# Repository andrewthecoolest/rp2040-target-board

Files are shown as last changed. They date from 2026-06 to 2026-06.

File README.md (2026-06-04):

# RP2040 Target Board

A ChipWhisperer-compatible target board built around the Raspberry Pi RP2040.

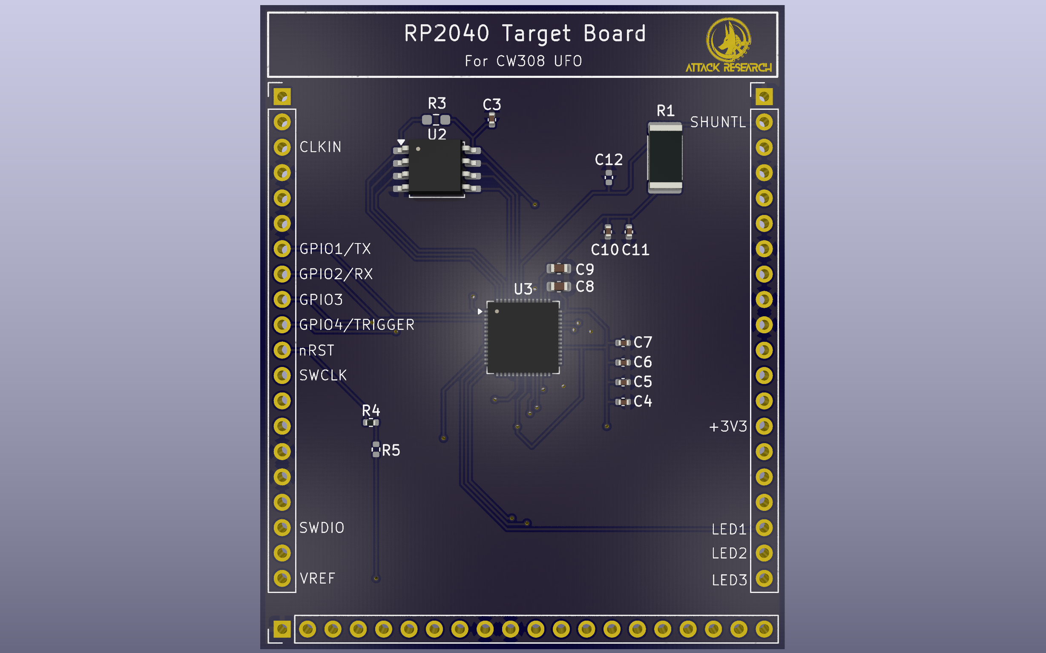
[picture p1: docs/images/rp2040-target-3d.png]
board


## Overview

This board connects an RP2040 with shunt to the CW308 UFO.

## Features

- RP2040 dual-core Arm Cortex-M0+ microcontroller
- 16MB QSPI flash
- ChipWhisperer 60-pin UFO308 target connector
- 5Ω shunt (changable to anything < 10Ω)
- 2-layer PCB
- Made with love

## Ordering

If you want to make your own, Gerbers are in `fab/gerbers/`. I made it with JLCPCB default 2-layer settings, so I included CPL and BOM for JLCPCB. For JLCPCB specifically, I've already zipped the gerbers and drill.

## Repository Structure

```
├── hardware/
│   ├── rp2040-target.kicad_pro     KiCad project
│   ├── rp2040-target.kicad_pcb     PCB
│   ├── rp2040-target.kicad_sch     Main schematic
│   ├── rp2040-target.kicad_wks     AR template
│   ├── RP2040.kicad_sch            RP2040 sub-sheet
│   ├── Flash.kicad_sch             Flash sub-sheet
│   └── libs/
│       ├── Conn_UFO308.kicad_sym   UFO308 target schematic symbol
│       └── UFO308.pretty/          UFO308 target footprint
│
├── fab/
│   ├── gerbers/                    Gbrs and drill
│   ├── 2040-target-fab.zip         Gerber and drill zip
│   ├── jlcpcb_bom.csv              BOM
│   └── jlcpcb_cpl.csv              CPL
│
└── docs/
    ├── schematic.pdf
    └── images/
```

## Andrew Acknowledgement

Start Message.
    My name is Andrew ᶘ ◕ᴥ◕ᶅ
Conclude Message.

## License

Copyright Attack Research 2026. Licensed under the [CERN Open Hardware Licence Version 2 - Permissive (CERN-OHL-P v2)](LICENSE).

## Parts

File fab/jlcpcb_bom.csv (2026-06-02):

Comment | Designator | Footprint | JLCPCB Part #
100nF | C3, C4, C5, C6, C7, C10, C11 | C_0402_1005Metric | C1525
1uF | C8, C9 | C_0603_1608Metric | C1592
DNP | C12 | C_0402_1005Metric
5Ω Shunt | R1 | R_2512_6332Metric | C5123609
DNP | R3 | R_0603_1608Metric_Pad0.98x0.95mm_HandSolder
0Ω | R4 | R_0402_1005Metric | C17168
DNP | R5 | R_0402_1005Metric
W25Q128JVS | U2 | SOIC-8_5.3x5.3mm_P1.27mm | C97521
RP2040 | U3 | QFN-56-1EP_7x7mm_P0.4mm_EP3.2x3.2mm | C2040

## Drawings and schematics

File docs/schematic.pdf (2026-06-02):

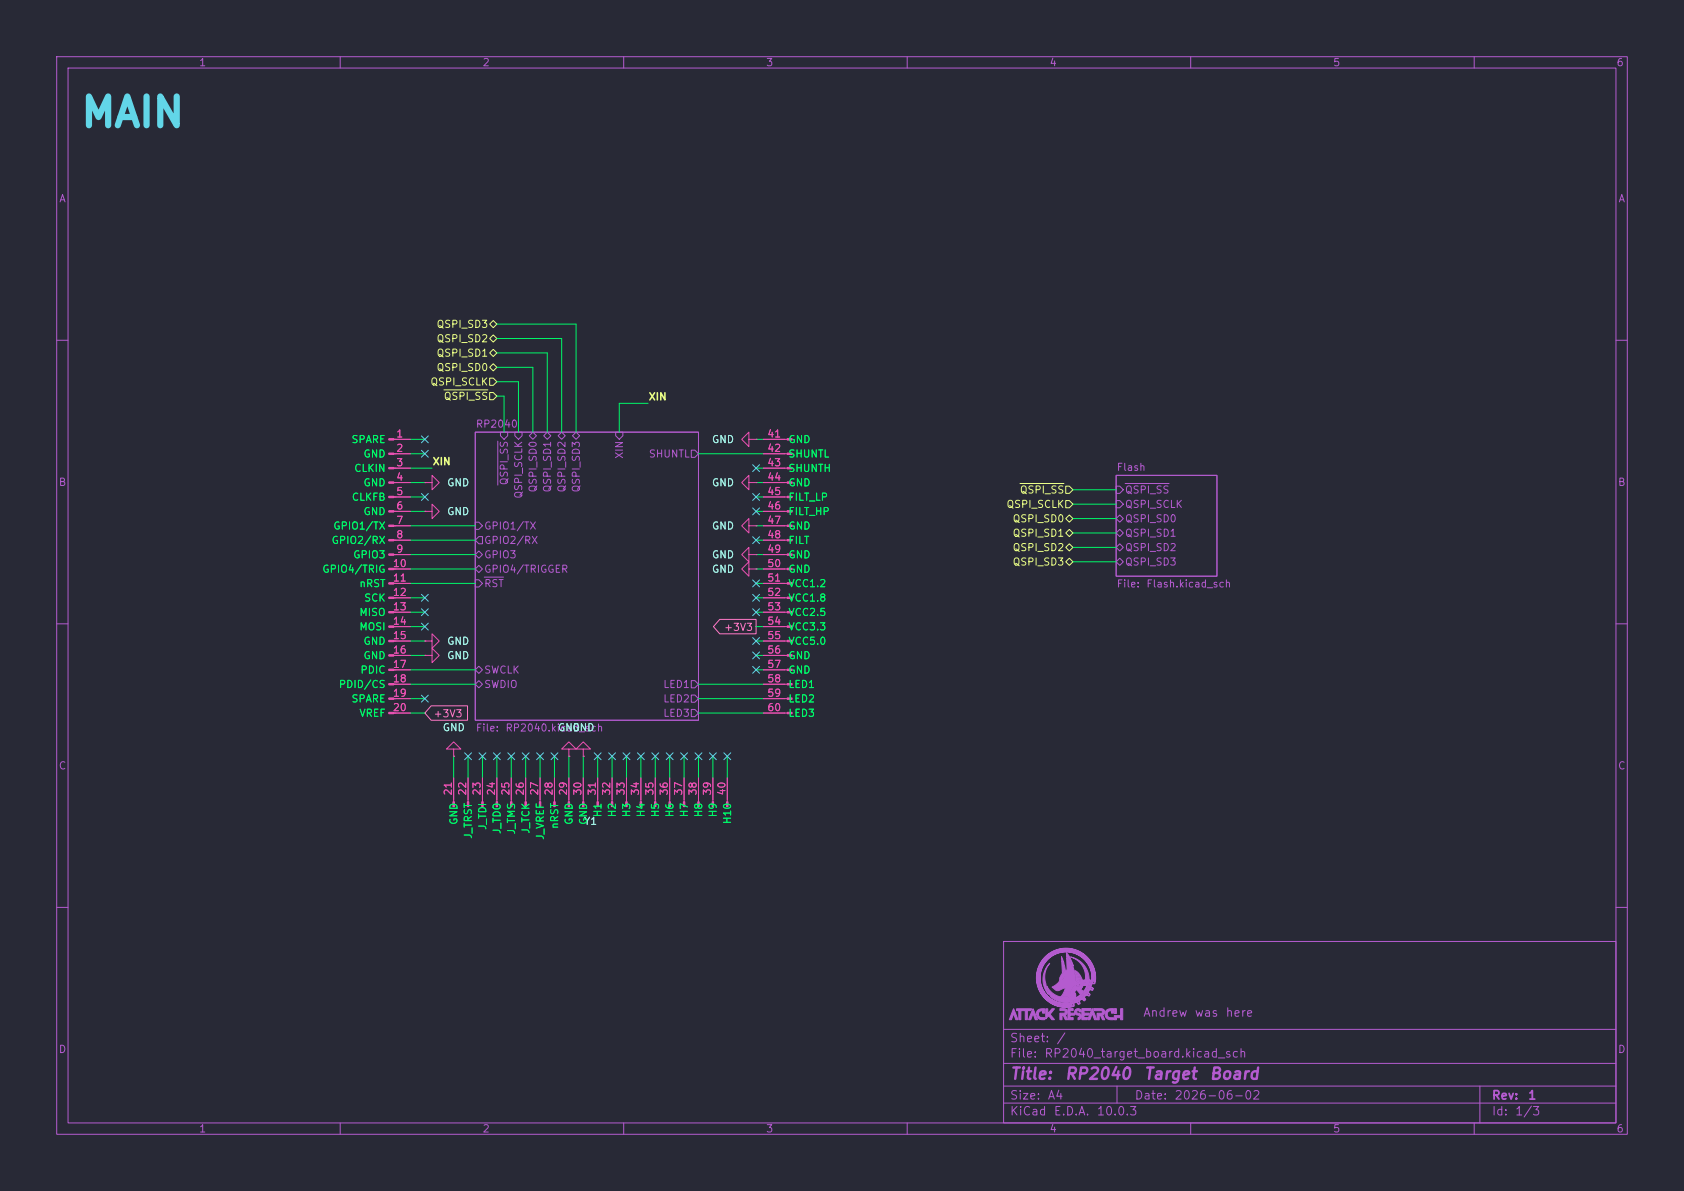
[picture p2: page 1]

SPARE 1 GND 2 CLKIN 3 GND 4 CLKFB 5 GND 6 GPIO1/TX 7 GPIO2/RX 8 GPIO3 9 GPIO4/TRIG 10

nRST 11
SCK 12 MISO 13 MOSI 14 GND 15 GND 16 PDIC 17 PDID/CS 18

Size: A4 | Rev: 1
KiCad E.D.A. 10.0.3 | Id: 1/3

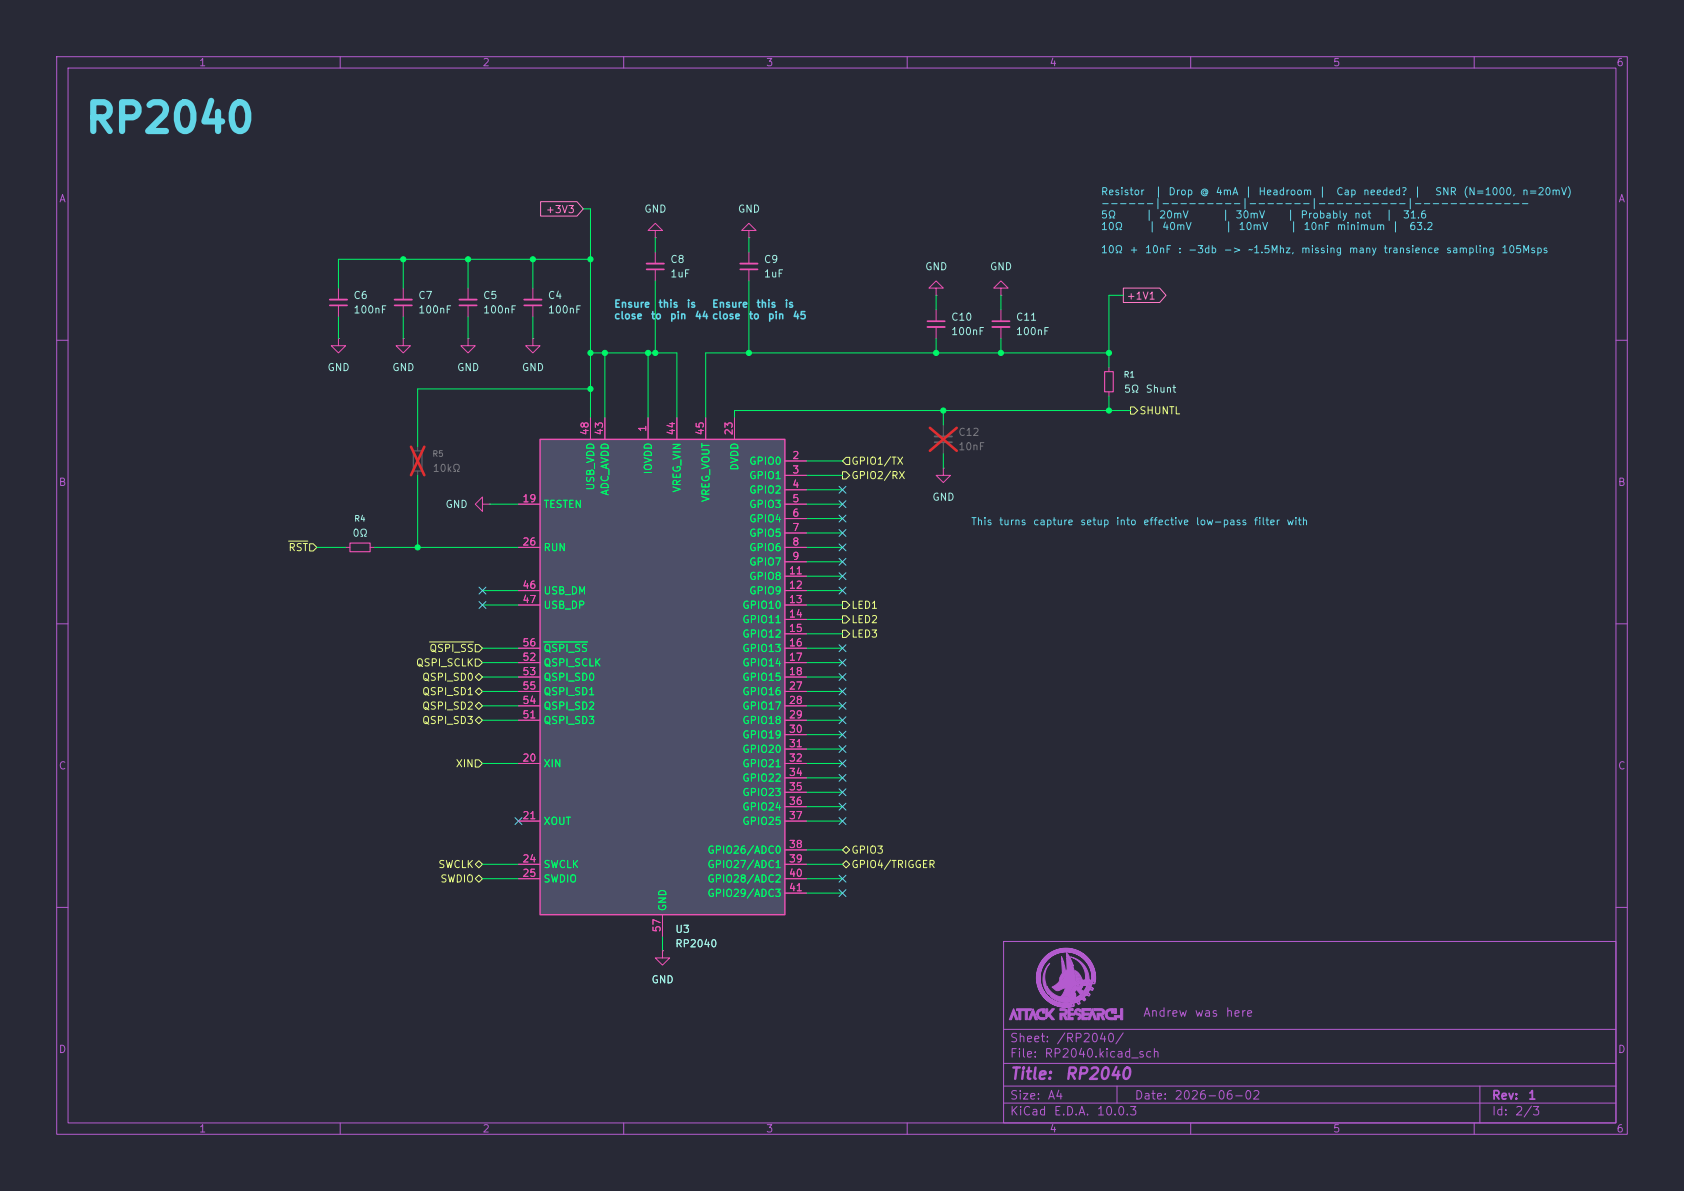
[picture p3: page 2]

This turns capture setup into effective low-pass filter with RP2040

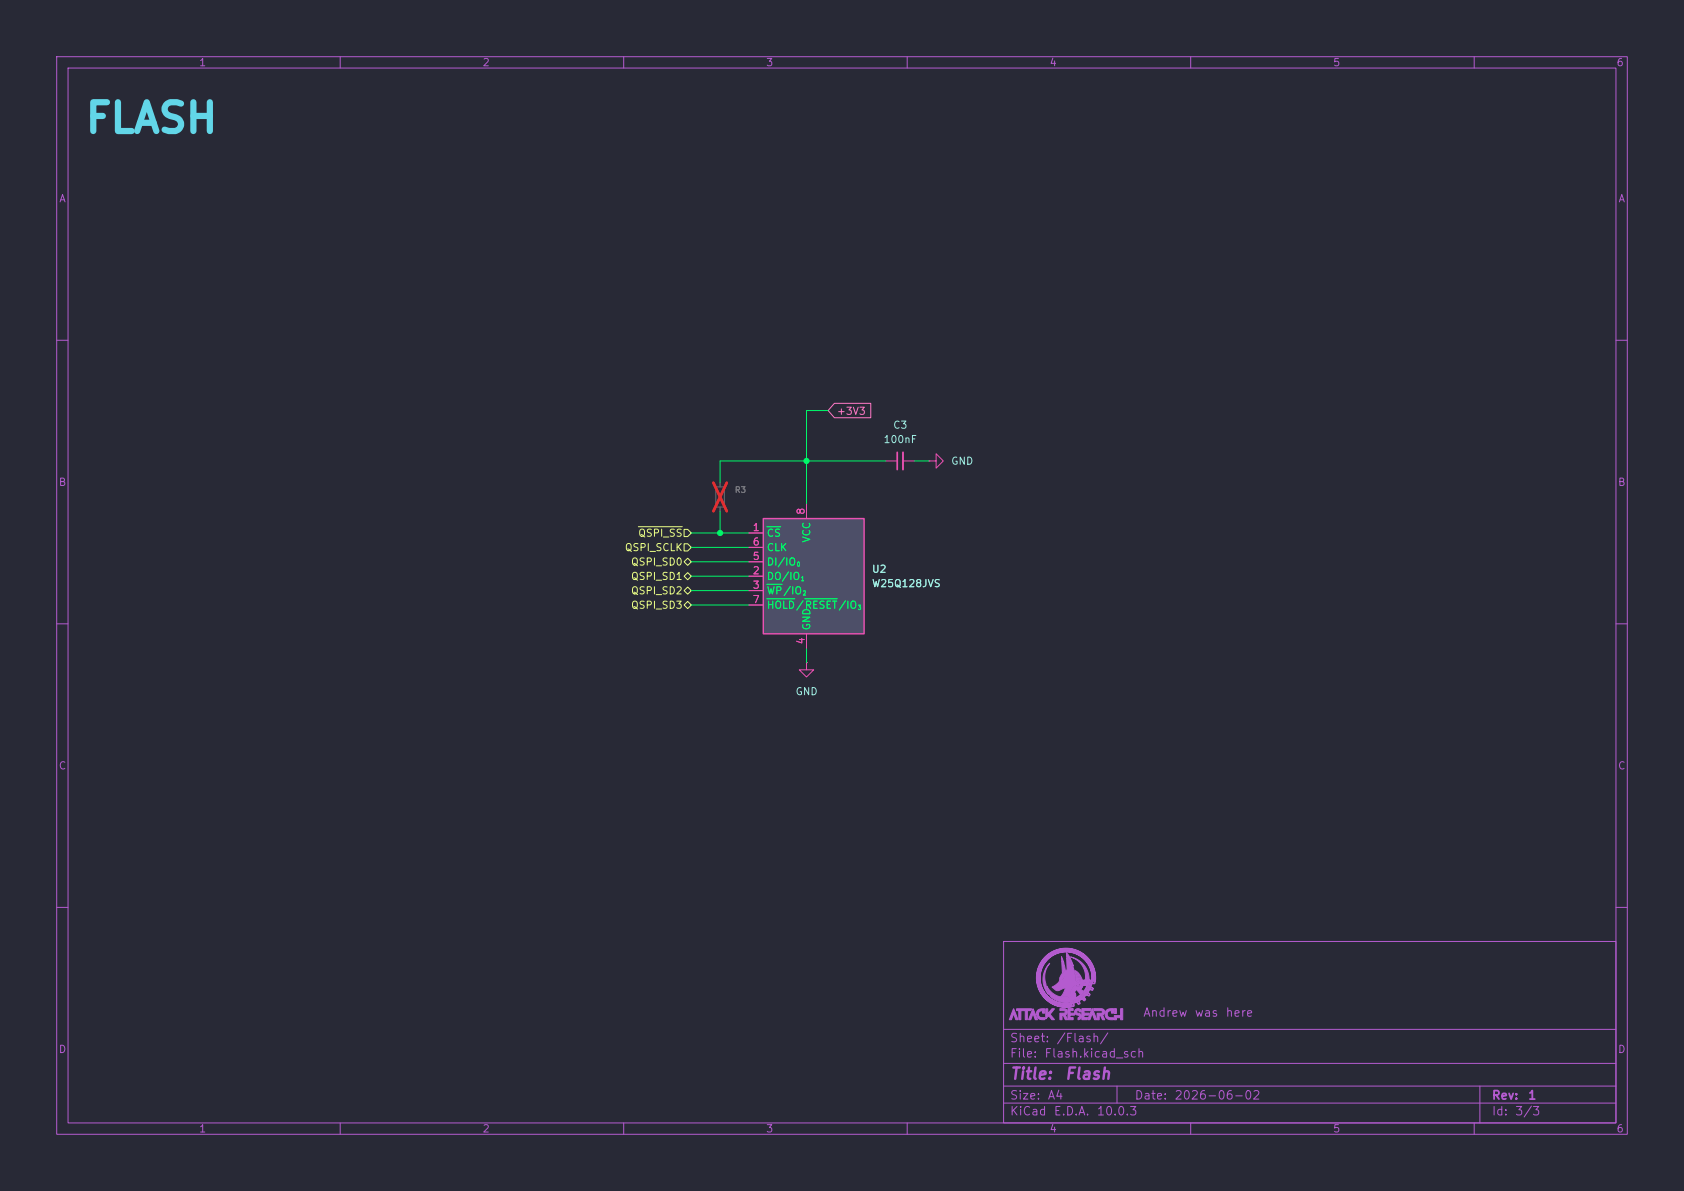
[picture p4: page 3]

4 DI/IO0 5 CLK 6 HOLD/RESET/IO3 7 VCC

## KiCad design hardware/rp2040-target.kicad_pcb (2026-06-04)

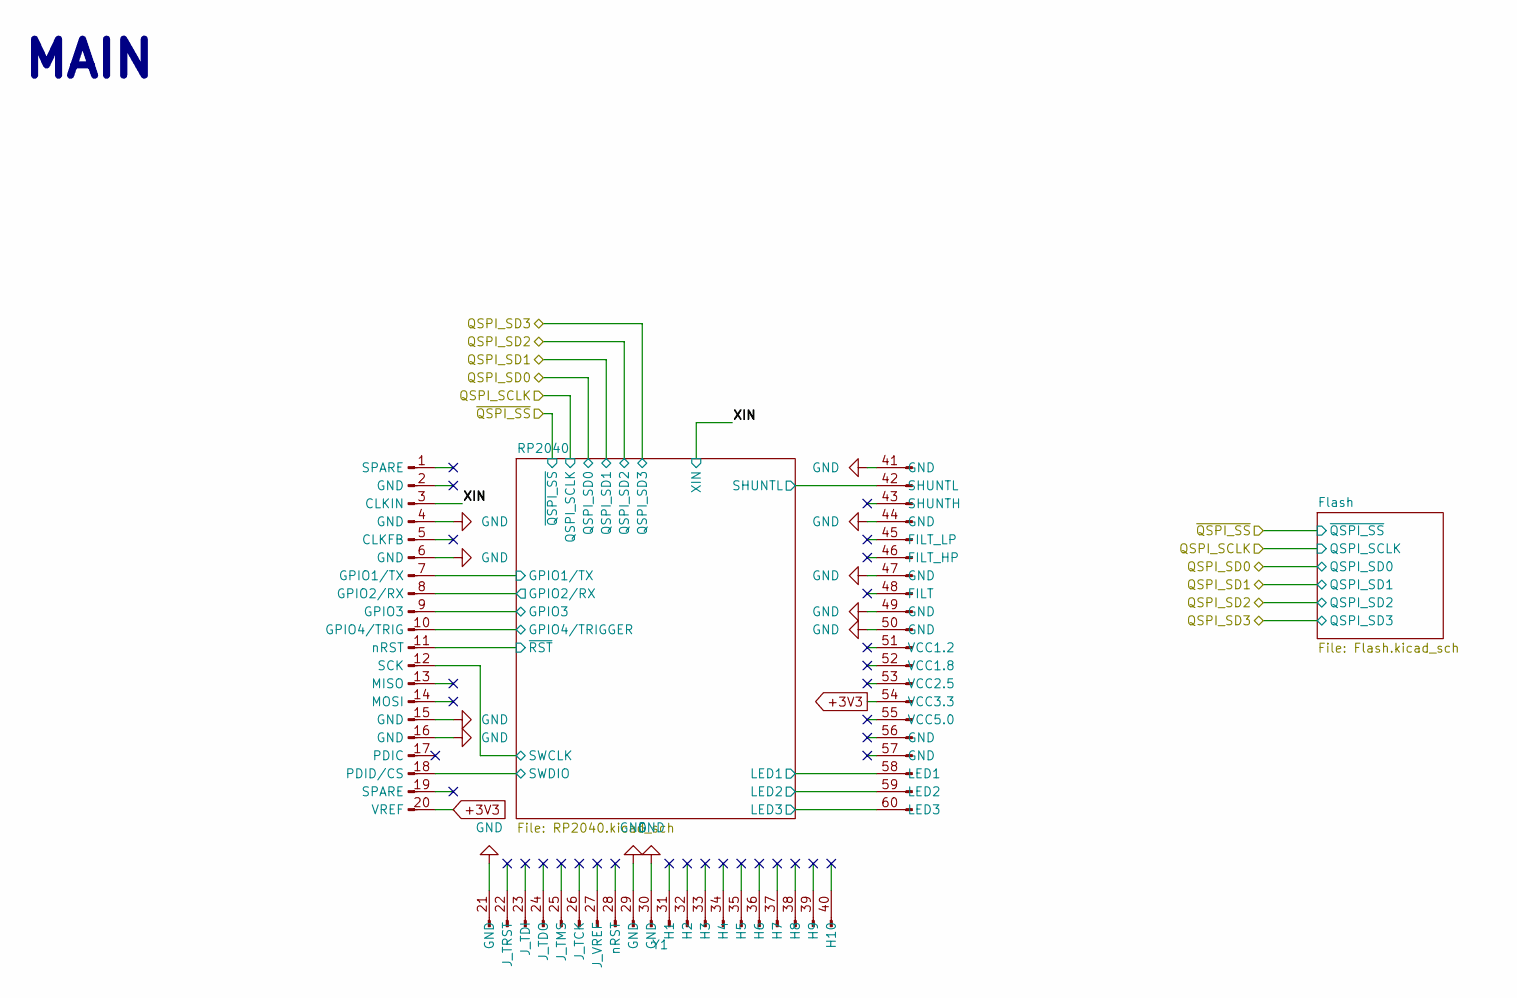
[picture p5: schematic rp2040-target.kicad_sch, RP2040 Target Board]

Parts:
Y1: Conn_UFO308_Target

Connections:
+3V3: Y1.20 (VREF), Y1.54 (VCC3.3); also elsewhere on the board
/RP2040/GPIO1/TX: Y1.7 (GPIO1/TX); also elsewhere on the board
/RP2040/GPIO2/RX: Y1.8 (GPIO2/RX); also elsewhere on the board
/RP2040/GPIO3: Y1.9 (GPIO3); also elsewhere on the board
/RP2040/GPIO4/TRIGGER: Y1.10 (GPIO4/TRIG); also elsewhere on the board
/RP2040/LED1: Y1.58 (LED1); also elsewhere on the board
/RP2040/LED2: Y1.59 (LED2); also elsewhere on the board
/RP2040/LED3: Y1.60 (LED3); also elsewhere on the board
/RP2040/SHUNTL: Y1.42 (SHUNTL); also elsewhere on the board
/RP2040/SWCLK: Y1.12 (SCK); also elsewhere on the board
/RP2040/SWDIO: Y1.18 (PDID/CS); also elsewhere on the board
/RP2040/~RST: Y1.11 (nRST); also elsewhere on the board
/XIN: Y1.3 (CLKIN); also elsewhere on the board
GND: Y1.4 (GND), Y1.6 (GND), Y1.15 (GND), Y1.16 (GND), Y1.21 (GND), Y1.29 (GND), Y1.30 (GND), Y1.41 (GND), Y1.44 (GND), Y1.47 (GND), Y1.49 (GND), Y1.50 (GND); also elsewhere on the board

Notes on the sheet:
MAIN

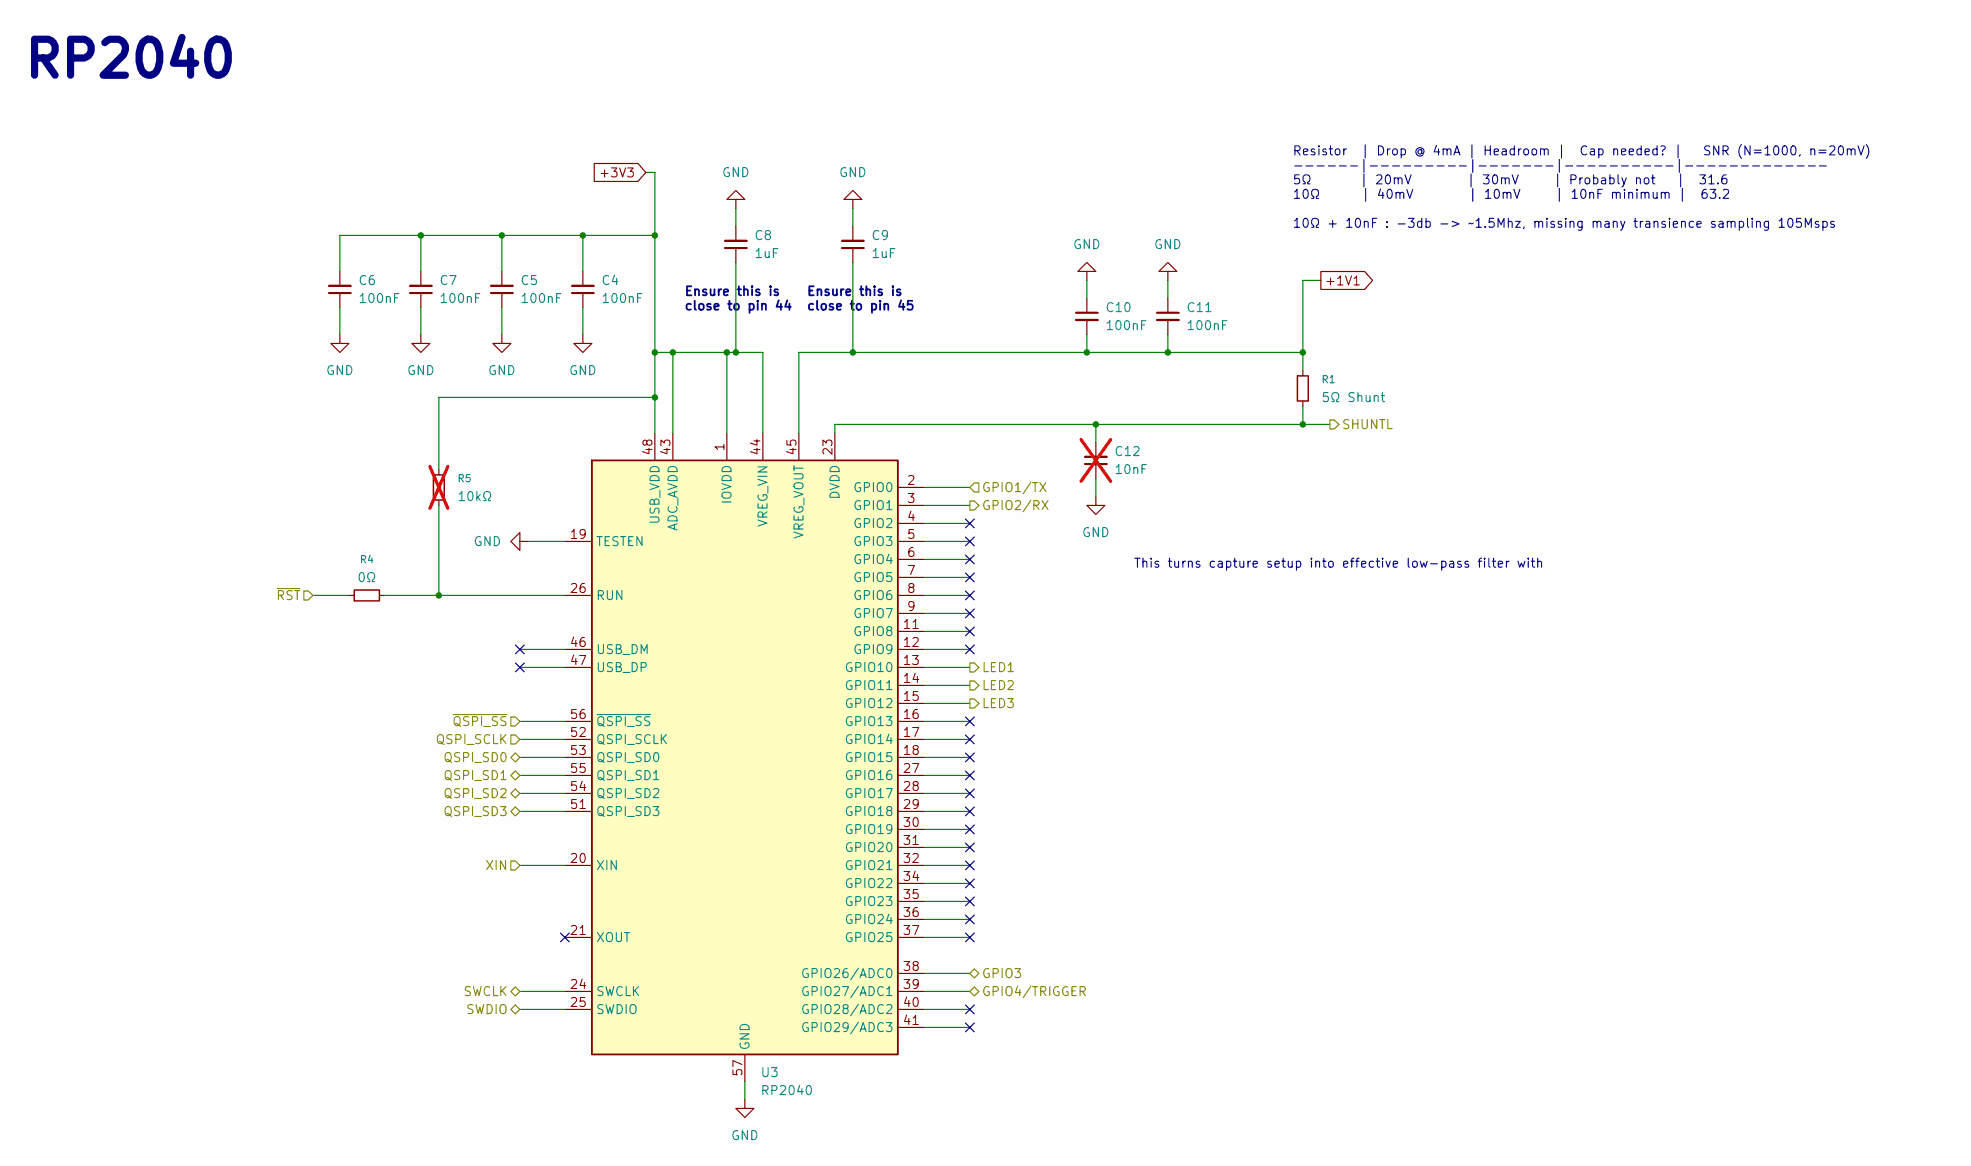
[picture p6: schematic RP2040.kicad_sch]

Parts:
C4, C5, C6, C7, C10, C11: 100nF; C_0402_1005Metric; JLC C1525
C8, C9: 1uF; C_0603_1608Metric; JLC C1592
C12: 10nF; C_0402_1005Metric; JLC C1524; not fitted
R1: 5Ω Shunt; R_2512_6332Metric; JLC C5123609
R4: 0Ω; R_0402_1005Metric; JLC C17168
R5: 10kΩ; R_0402_1005Metric; JLC C17168; not fitted
U3: RP2040; QFN-56-1EP_7x7mm_P0.4mm_EP3.2x3.2mm; JLC C2040

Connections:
+1V1: C9.1, C10.2, C11.2, R1.1, U3.45 (VREG_VOUT)
+3V3: C4.2, C5.2, C6.2, C7.2, C8.1, R5.2, U3.1 (IOVDD), U3.10 (IOVDD), U3.22 (IOVDD), U3.33 (IOVDD), U3.42 (IOVDD), U3.43 (ADC_AVDD), U3.44 (VREG_VIN), U3.48 (USB_VDD), U3.49 (IOVDD); also elsewhere on the board
/QSPI_SCLK: U3.52 (QSPI_SCLK); also elsewhere on the board
/QSPI_SD0: U3.53 (QSPI_SD0); also elsewhere on the board
/QSPI_SD1: U3.55 (QSPI_SD1); also elsewhere on the board
/QSPI_SD2: U3.54 (QSPI_SD2); also elsewhere on the board
/QSPI_SD3: U3.51 (QSPI_SD3); also elsewhere on the board
/RP2040/GPIO1/TX: U3.2 (GPIO0); also elsewhere on the board
/RP2040/GPIO2/RX: U3.3 (GPIO1); also elsewhere on the board
/RP2040/GPIO3: U3.38 (GPIO26/ADC0); also elsewhere on the board
/RP2040/GPIO4/TRIGGER: U3.39 (GPIO27/ADC1); also elsewhere on the board
/RP2040/LED1: U3.13 (GPIO10); also elsewhere on the board
/RP2040/LED2: U3.14 (GPIO11); also elsewhere on the board
/RP2040/LED3: U3.15 (GPIO12); also elsewhere on the board
/RP2040/SHUNTL: C12.2, R1.2, U3.23 (DVDD), U3.50 (DVDD); also elsewhere on the board
/RP2040/SWCLK: U3.24 (SWCLK); also elsewhere on the board
/RP2040/SWDIO: U3.25 (SWDIO); also elsewhere on the board
/RP2040/~RST: R4.1; also elsewhere on the board
/XIN: U3.20 (XIN); also elsewhere on the board
/~QSPI_SS: U3.56 (~QSPI_SS); also elsewhere on the board
GND: C4.1, C5.1, C6.1, C7.1, C8.2, C9.2, C10.1, C11.1, C12.1, U3.19 (TESTEN), U3.57 (GND); also elsewhere on the board
unnamed: R4.2, R5.1, U3.26 (RUN)

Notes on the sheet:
RP2040
Ensure this is close to pin 45
Resistor | Drop @ 4mA | Headroom | Cap needed? | SNR (N=1000, n=20mV) ------|---------|-------|----------|------------- 5Ω | 20mV | 30mV | Probably not | 31.6 10Ω | 40mV | 10mV | 10nF minimum | 63.2 10Ω + 10nF : -3db -> ~1.5Mhz, missing many transience sampling 105Msps
Ensure this is close to pin 44
This turns capture setup into effective low-pass filter with

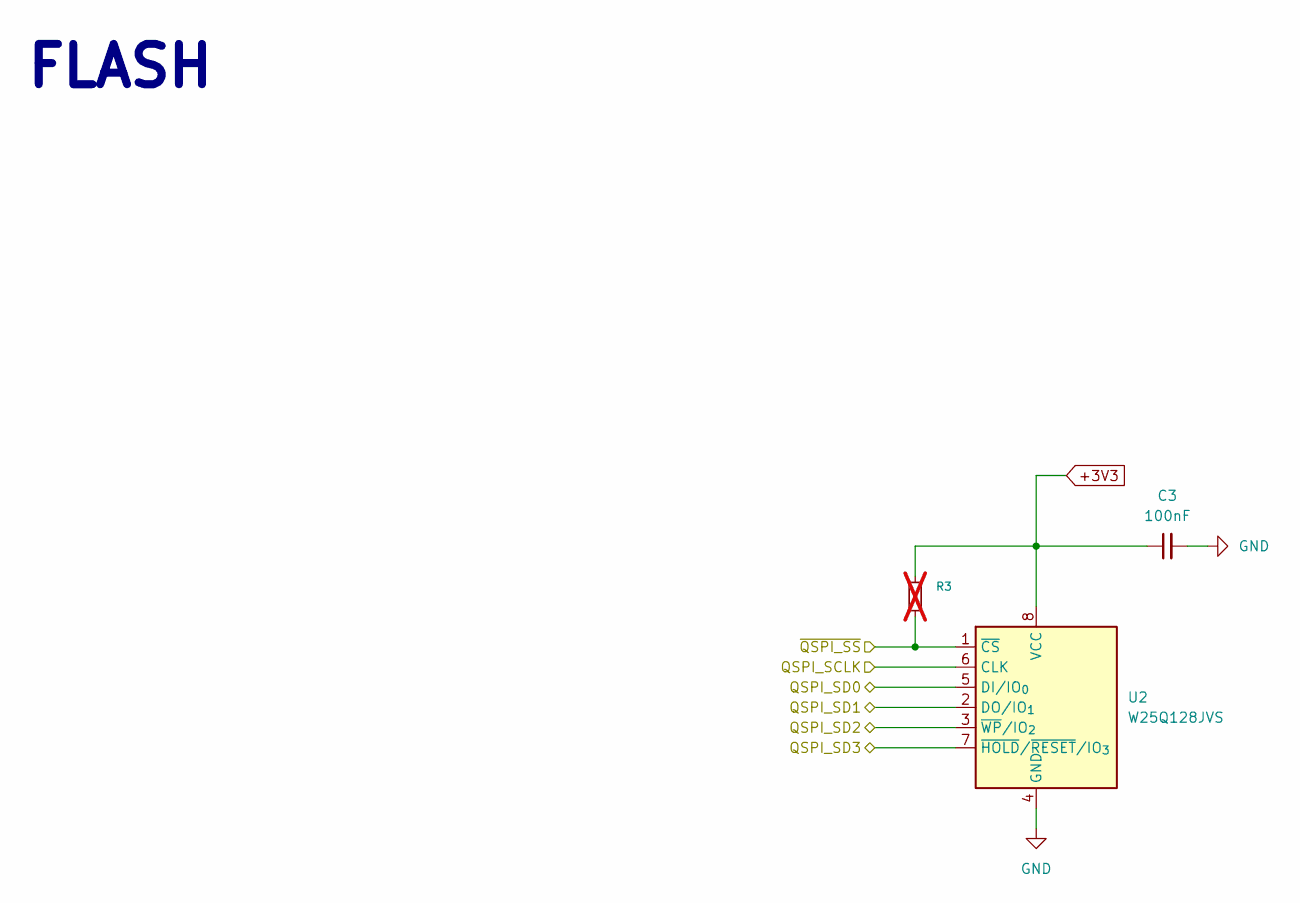
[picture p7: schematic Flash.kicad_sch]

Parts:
C3: 100nF; C_0402_1005Metric; JLC C1525
R3: R_0603_1608Metric_Pad0.98x0.95mm_HandSolder; not fitted
U2: W25Q128JVS; SOIC-8_5.3x5.3mm_P1.27mm; JLC C97521

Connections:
+3V3: C3.1, R3.1, U2.8 (VCC); also elsewhere on the board
/QSPI_SCLK: U2.6 (CLK); also elsewhere on the board
/QSPI_SD0: U2.5 (DI/IO_{0}); also elsewhere on the board
/QSPI_SD1: U2.2 (DO/IO_{1}); also elsewhere on the board
/QSPI_SD2: U2.3 (~WP/IO_{2}); also elsewhere on the board
/QSPI_SD3: U2.7 (~HOLD/~RESET/IO_{3}); also elsewhere on the board
/~QSPI_SS: R3.2, U2.1 (~CS); also elsewhere on the board
GND: C3.2, U2.4 (GND); also elsewhere on the board

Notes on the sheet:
FLASH

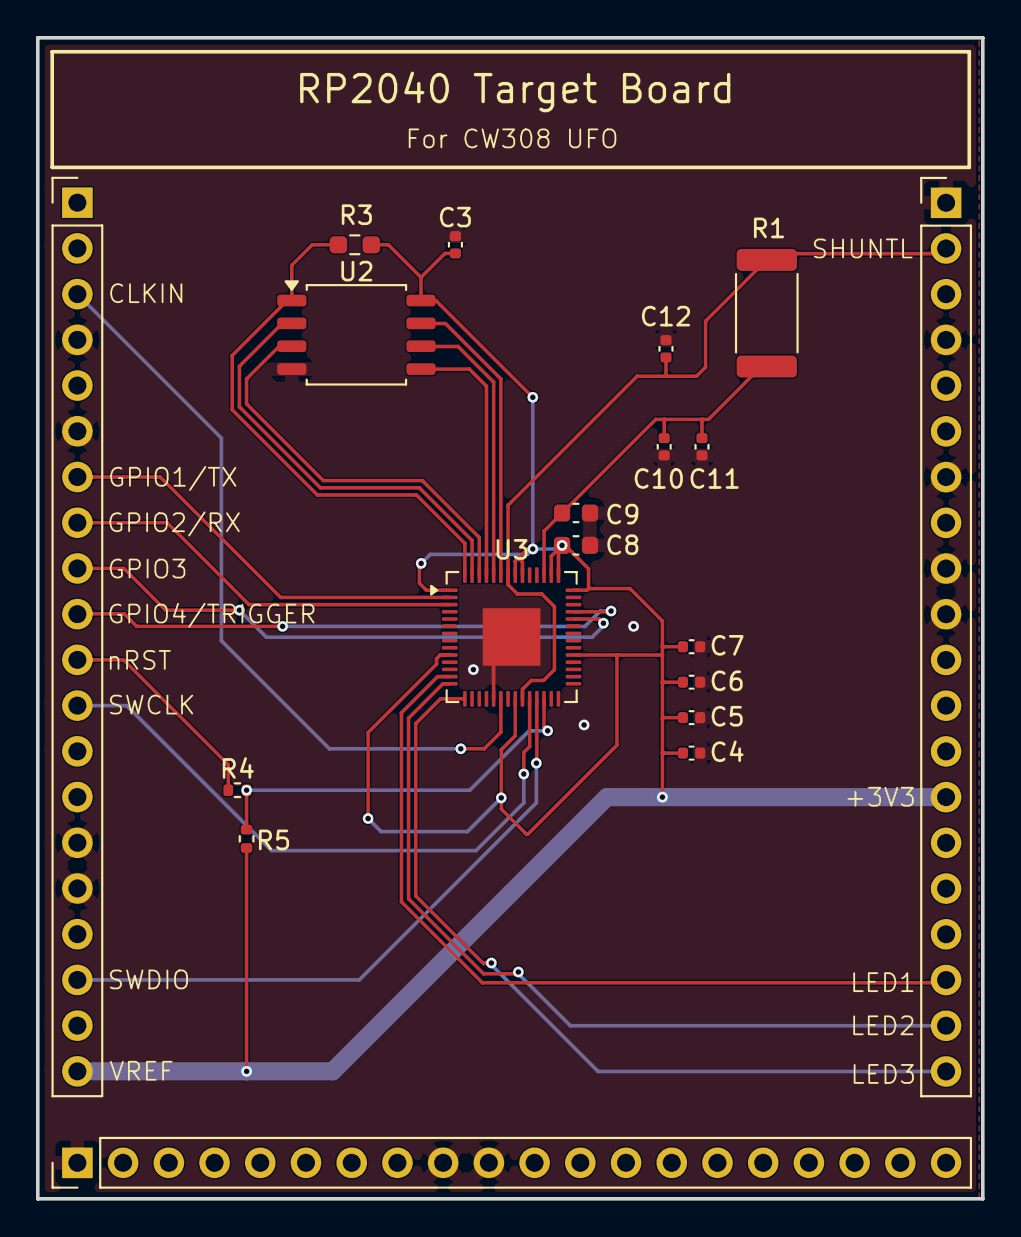
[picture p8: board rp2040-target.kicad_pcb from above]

Board: 2 copper layers, 52.5 x 64.5 mm, 17 parts (0 on the bottom side), 22 nets.

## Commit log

2026-06-02 push it push it
    [Flash.kicad_sch, RP2040.kicad_sch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]
2026-06-02 add ᶘ ◕ᴥ◕ ᶅ
2026-06-02 small changes
    [jlcpcb_bom.csv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]
2026-06-04 SCK change
    [Flash.kicad_sch, RP2040.kicad_sch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]
